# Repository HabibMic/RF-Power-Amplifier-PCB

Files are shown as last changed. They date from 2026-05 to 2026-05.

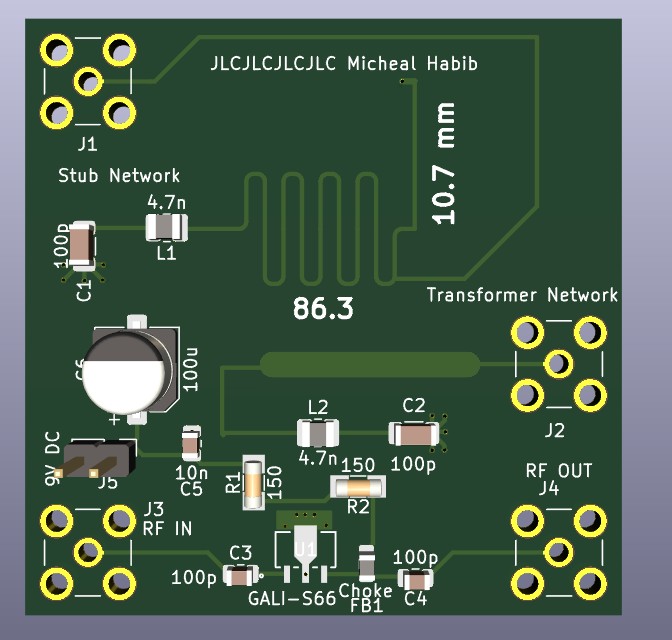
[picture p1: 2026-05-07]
Docs/3D.jpg

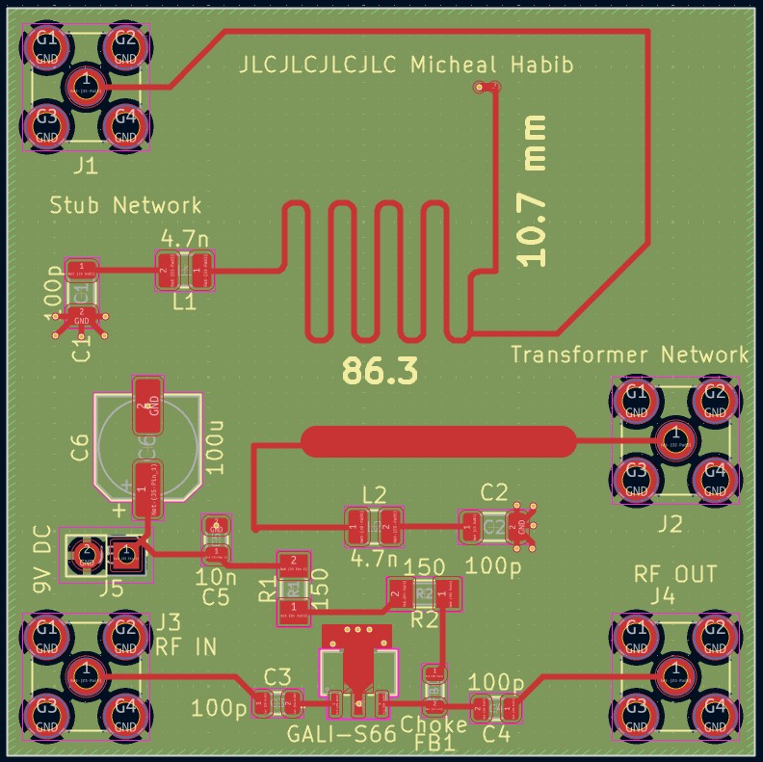
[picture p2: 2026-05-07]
Docs/PCB.jpg

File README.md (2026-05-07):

# RF Power Amplifier & Impedance Matching System

## Overview
This repository contains the design and 4-layer PCB layout for a high-frequency RF power amplifier. The system features an active gain stage and two separate impedance matching networks designed to interface a non-standard "test load" with a 50 Ohm system.

## Design Specifications

### 1. Active RF Gain Block
* **Amplifier**: Based on the Mini-Circuits GALI-S66 integrated circuit.
* **Biasing**: Utilizes a 9V DC supply with a 300 Ohm total bias resistance (implemented as two 150 Ohm resistors in series) to set stable operating current.
* **RF Isolation**: Employs a Ferrite Bead (FB1) as an RF choke to isolate the DC path from high-frequency signals.
* **Coupling & Decoupling**: Includes 100pF DC-blocking capacitors at the input and output ports, and a decoupling array (10nF and 100uF) to filter power supply ripple.

### 2. Impedance Matching Networks
* **Short-Circuit Shunt Stub**: Calculated via Smith Chart analysis for a physical distance of 86.3 and a stub length of 10.7 mm.
* **Quarter-Wave Transformer**: A lambda/4 transmission line section with a calculated characteristic impedance of 70.7 Ohms.

## PCB Manufacturing
* **Form Factor**: 48.26 mm x 48.26 mm, compliant with 5 cm x 5 cm laboratory constraints.
* **Stackup**: JLC04161H-7628 4-layer standard configuration.
* **Layer Strategy**: 
    * **Top Layer**: Signal routing and RF microstrip lines.
    * **Internal Layer 1**: Dedicated ground plane for impedance control.
    * **Internal Layer 2**: Power plane.
* **Thermal Management**: Via-stitching array implemented under the GALI-S66 thermal pad for heat transfer to internal planes.

## Lab Characterization
Testing was performed using a Keysight N9912A FieldFox Vector Network Analyzer.
* **Measurement**: S-parameter characterization (S11, S21) across a 50 to 150 MHz sweep.
* **Calibration**: Applied port extension techniques to null out phase delays from coaxial test cables.

---
**Author**: Micheal Habib

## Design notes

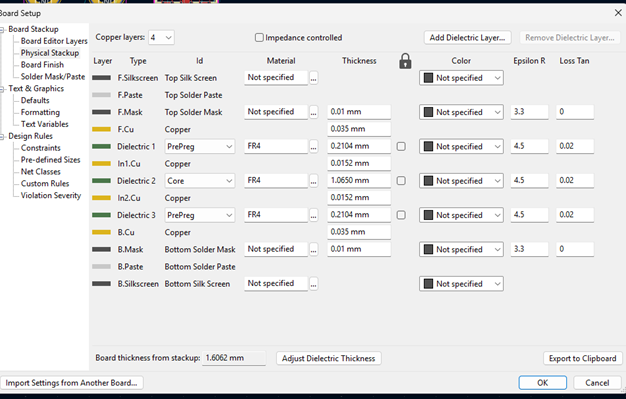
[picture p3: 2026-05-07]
Docs/Board_Stackup_Specs.png

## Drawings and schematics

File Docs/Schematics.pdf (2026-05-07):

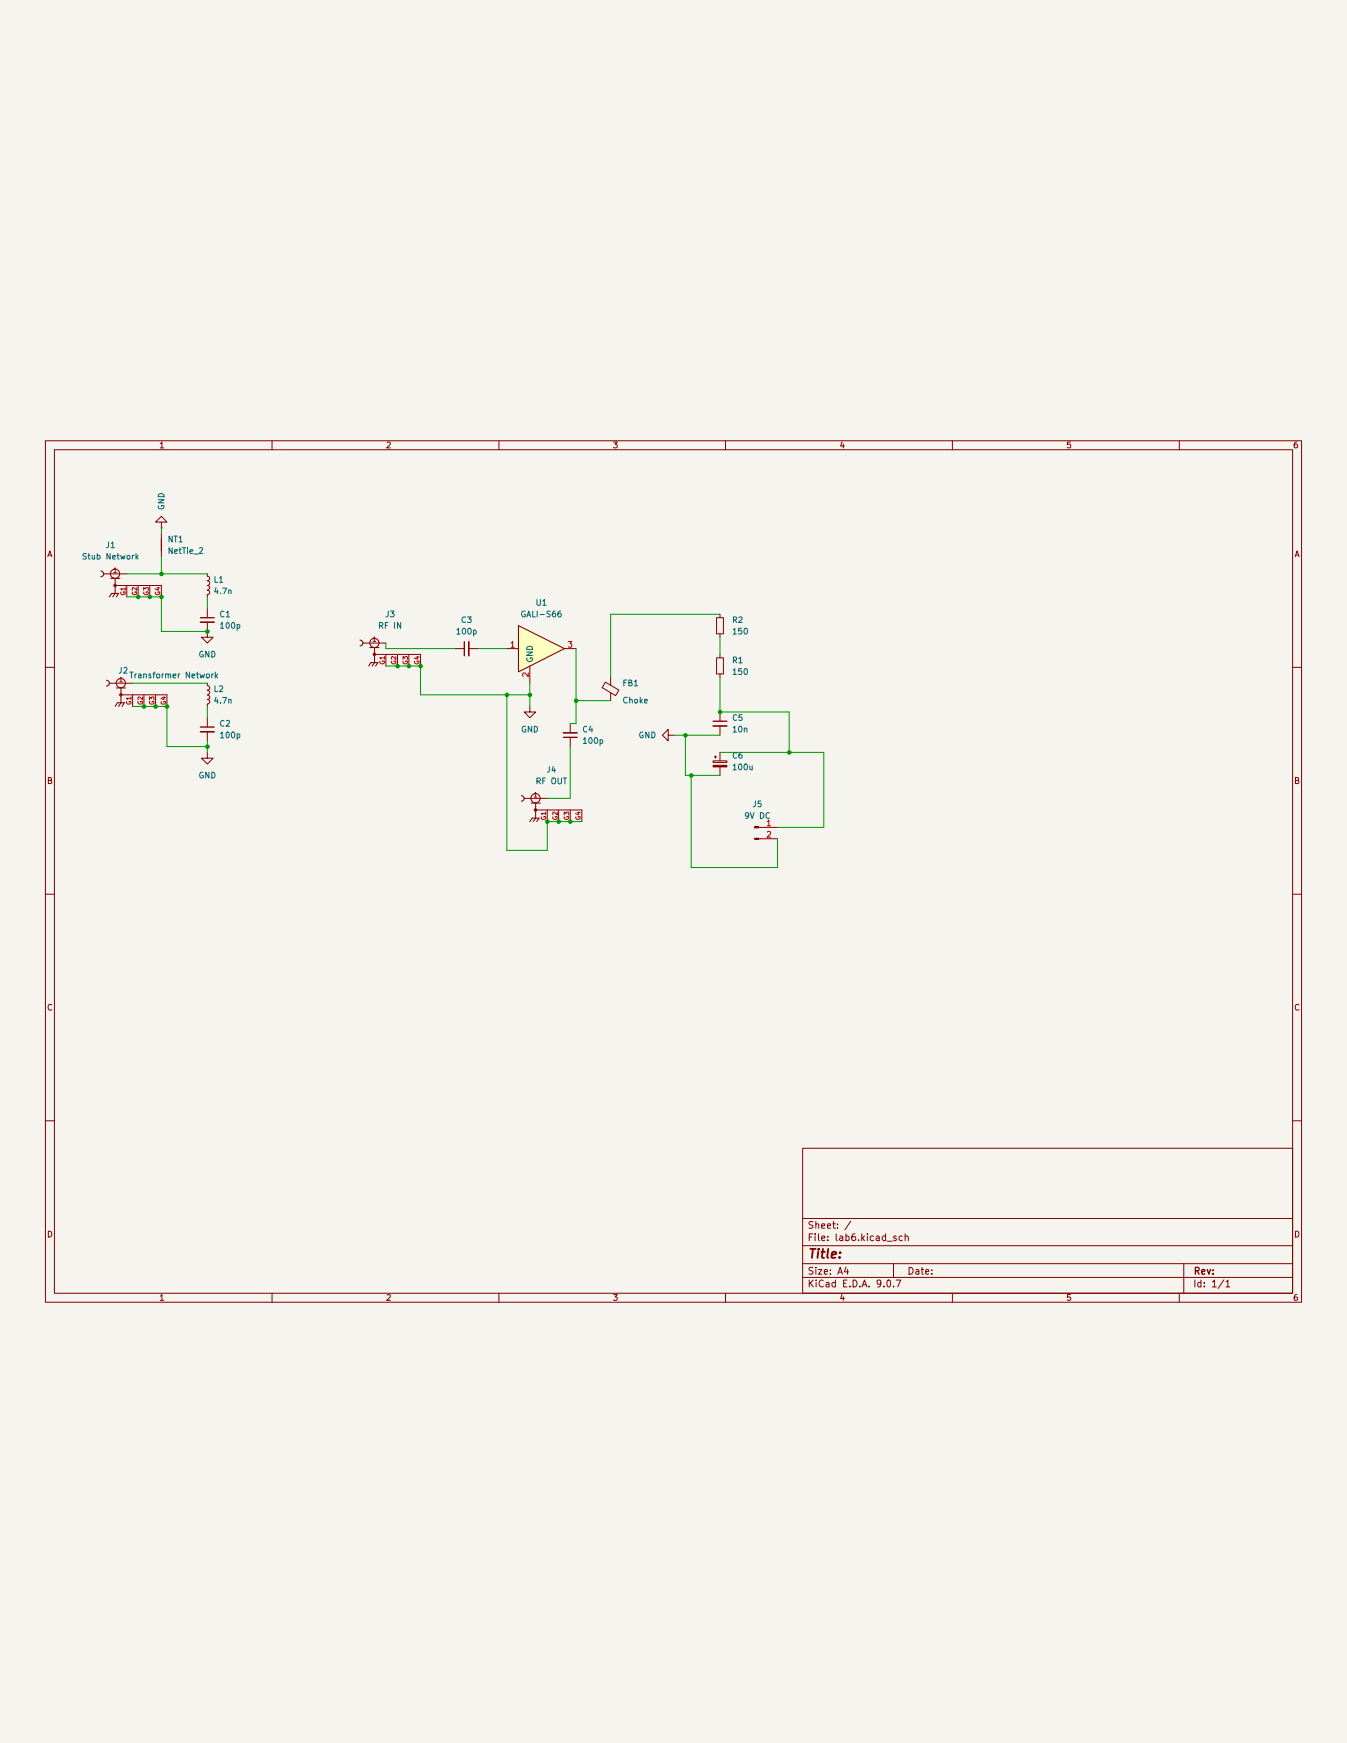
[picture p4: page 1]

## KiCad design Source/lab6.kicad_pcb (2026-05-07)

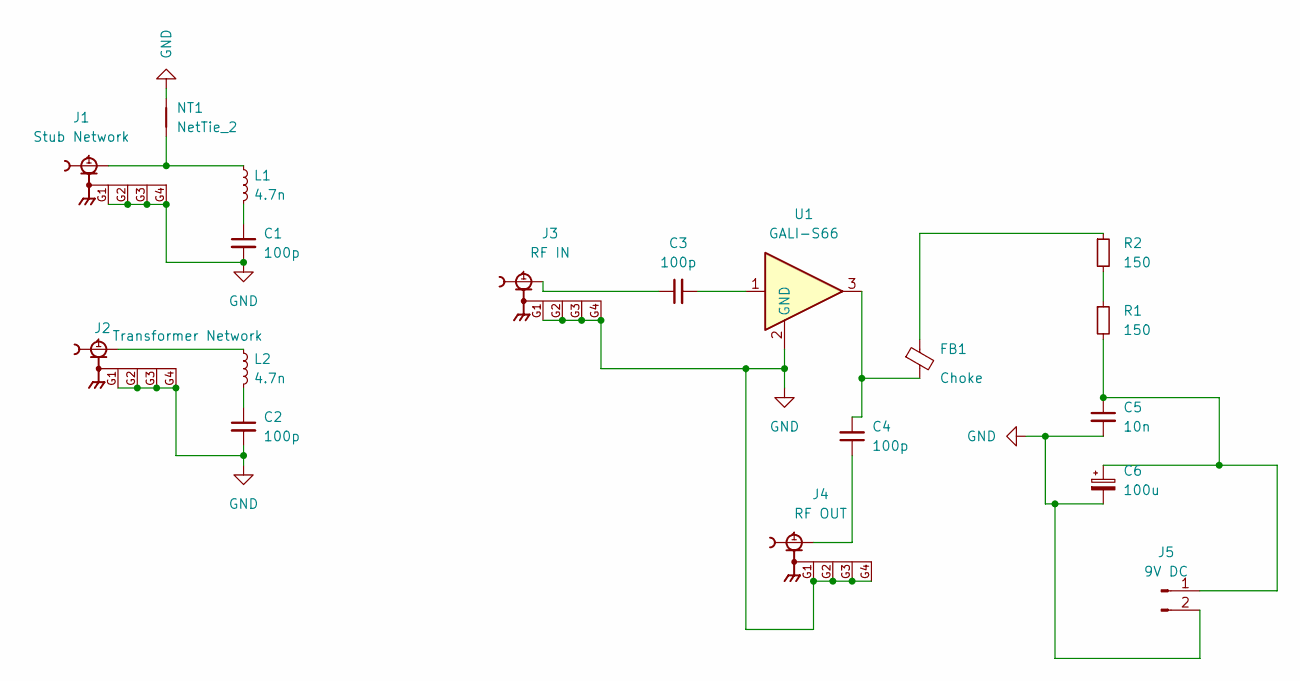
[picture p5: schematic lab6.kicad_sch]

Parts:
C1, C2: 100p; C_1206_3216Metric
C3, C4: 100p; C_0805_2012Metric
C5: 10n; C_0805_2012Metric
C6: 100u; CP_Elec_6.3x5.4_Nichicon
FB1: Choke; L_0805_2012Metric
J1: Stub Network; RFPC-SMA28-F; PARTREV 1.0
J2: Transformer Network; RFPC-SMA28-F; PARTREV 1.0
J3: RF IN; RFPC-SMA28-F; PARTREV 1.0
J4: RF OUT; RFPC-SMA28-F; PARTREV 1.0
J5: 9V DC; PinHeader_1x02_P2.54mm_Vertical
L1, L2: 4.7n; L_1008_2520Metric
NT1: NetTie_2; NetTie-2_SMD_Pad0.5mm
R1, R2: 150; R_MiniMELF_MMA-0204
U1: GALI-S66

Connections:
GND: C1.2, C2.2, C5.2, C6.2, J1.G1, J1.G2, J1.G3, J1.G4, J2.G1, J2.G2, J2.G3, J2.G4, J3.G1, J3.G2, J3.G3, J3.G4, J4.G1, J4.G2, J4.G3, J4.G4, J5.2, NT1.1, U1.2 (GND)
unnamed: C1.1, L1.2
unnamed: C2.1, L2.2
unnamed: C3.1, J3.1
unnamed: C3.2, U1.1
unnamed: C4.1, J4.1
unnamed: C4.2, FB1.2, U1.3
unnamed: FB1.1, R2.1
unnamed: J1.1, L1.1, NT1.2
unnamed: J2.1, L2.1
unnamed: C5.1, C6.1, J5.1, R1.2
unnamed: R1.1, R2.2

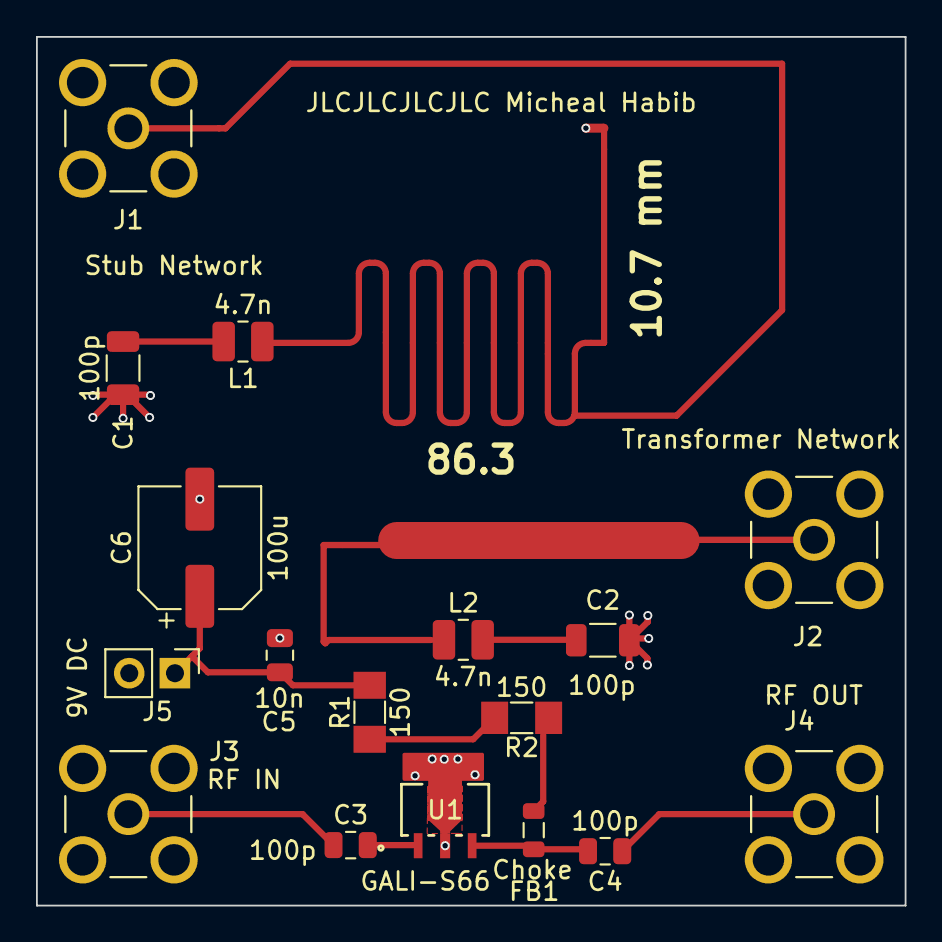
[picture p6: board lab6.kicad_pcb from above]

Board: 4 copper layers, 48.3 x 48.3 mm, 18 parts (0 on the bottom side), 12 nets.
